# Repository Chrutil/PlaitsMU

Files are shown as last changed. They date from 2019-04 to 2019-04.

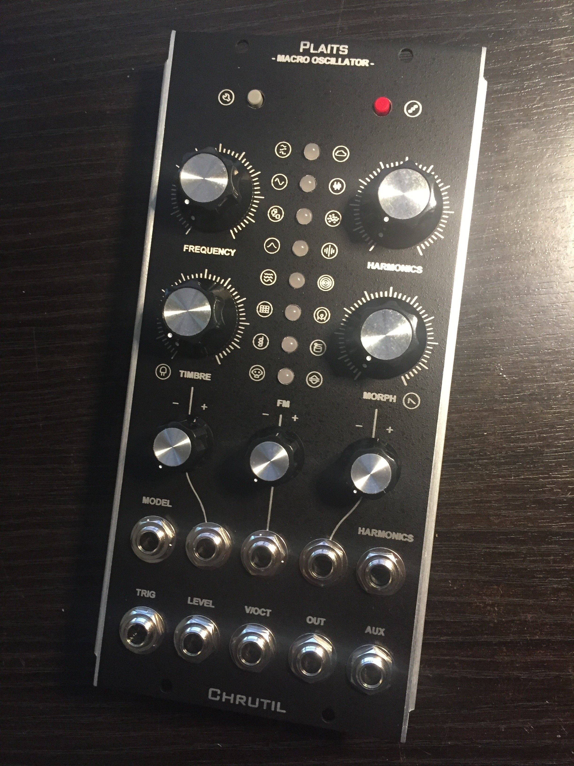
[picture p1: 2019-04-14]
front.jpg

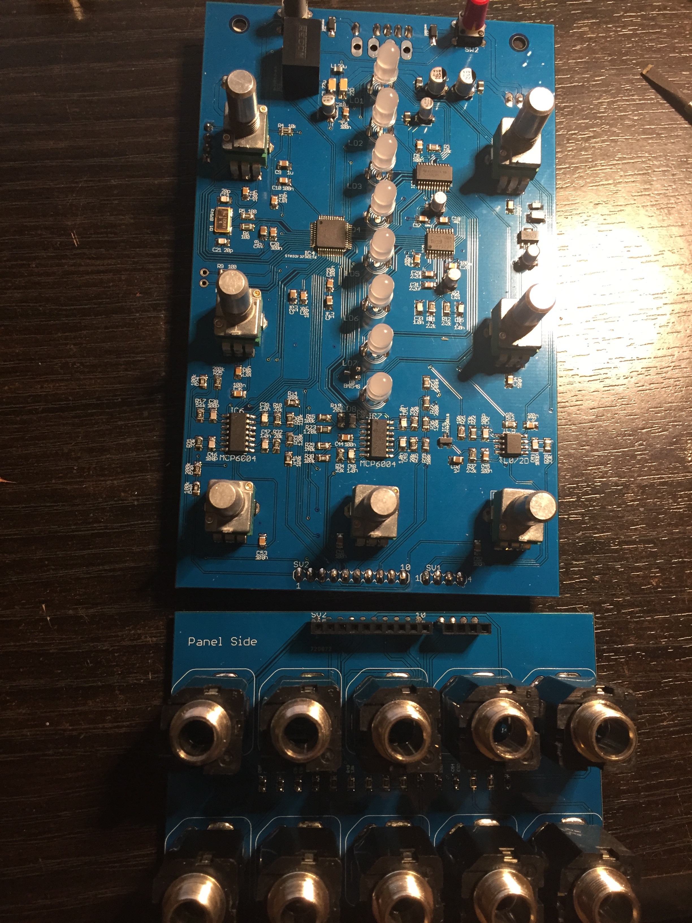
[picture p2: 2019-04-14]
populated_pcb.jpg

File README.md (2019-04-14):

# PlaitsMU
The Plaits Macro Oscillator ported to MU

This project is the Plaits Macro Oscillator by Mutable Instruments ported to MU large format modular.

The size of the PCB has been increased and the layout expanded for a 2MU module.
The footprint of most components have been changed to a larger 0805 size, for an easier build.
A few components were left at 0603 size where I could not find a suitable replacement.
The Power connector is a Synthesizers.com standard using -15v/+15v.
There are 12v power regulators added to feed the module the +/-12v it expects.
There is also a footprint for a MOTM power connector, but it is untested. 
I also suspect the io PCB is too wide for a double wide MOTM panel, but I have only tested MU so you are on your own there.

The best way is to select components is to look at the original BOM and pick the appropriate components with the expanded footprint.
I added a file with my parts selection, with no guarantees that I got it correct.

The STM32 mcu is the same as the original module and a very fine pitched IC with 0.5mm pitch so that will be the most challenging part.
I suggest starting with that one to make sure you got that right before populating the rest of the board.

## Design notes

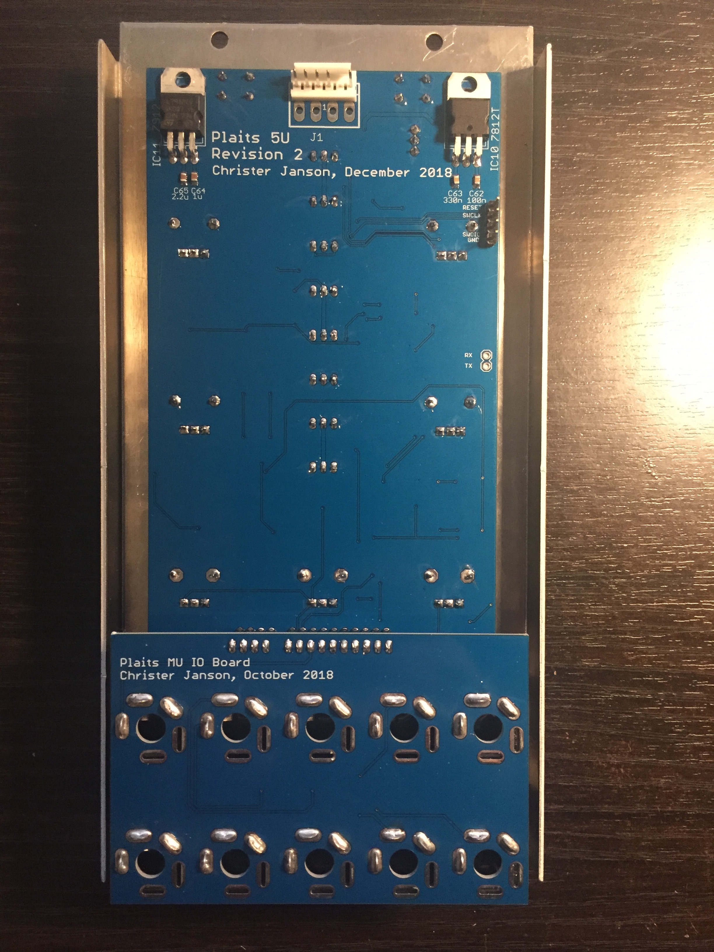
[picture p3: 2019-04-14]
back.jpg

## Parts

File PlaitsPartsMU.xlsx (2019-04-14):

Plaits, v5.0 [With MU replacement parts in green Column I]
Index | Qty | Description | Specs | Value | Package | Ref. Mouser | References | MU Part
SMT parts
R3, R4, R16, R21, R45, R48, R49, R50, R51 | 9 | Resistor | <=1%, 100mW | 10k | 0402 | 667-ERJ-2RKF1002X |  | Standard 0805 resistor
R5, R6, R9, R10 | 4 | Resistor | <=1%, 100mW | 100 | 0402 | 667-ERJ-2RKF1000X |  | Standard 0805 resistor
R11, R12, R37 | 3 | Resistor | <=1%, 100mW | 2.2k | 0402 | 667-ERJ-2RKF2201X |  | Standard 0805 resistor
R13, R14, R15, R24, R38, R39, R40, R41 | 8 | Resistor | <=1%, 100mW | 100k | 0402 | 667-ERJ-2RKF1003X |  | Standard 0805 resistor
R17 | 1 | Resistor | <=1%, 100mW | 56k | 0402 | 667-ERJ-2RKF5602X |  | Standard 0805 resistor
R18, R20, R22, R28, R31, R34 | 6 | Resistor | <=1%, 100mW | 33k | 0402 | 667-ERJ-2RKF3302X |  | Standard 0805 resistor
R19, R32, R35 | 3 | Resistor | <=1%, 100mW | 20k | 0402 | 667-ERJ-2RKF2002X |  | Standard 0805 resistor
R23, R33, R36 | 3 | Resistor | <=1%, 100mW | 120k | 0402 | 667-ERJ-2RKF1203X |  | Standard 0805 resistor
R25, R27, R30 | 3 | Resistor | <=1%, 100mW | 200k | 0402 | 667-ERJ-2RKF2003X |  | Standard 0805 resistor
R26 | 1 | Resistor | <=1%, 100mW | 110k | 0402 | 667-ERJ-2RKF1103X |  | Standard 0805 resistor
R29 | 1 | Resistor | <=1%, 100mW | 140k | 0402 | 667-ERJ-2RKF1403X |  | Standard 0805 resistor
R46, R47 | 2 | Resistor | <= 1%, >= 200mW | 1.0k | 0603 | 667-ERJ-PA3D1001V | Panasonic ERJ-PA3D1001V | same
C1, C2, C13 | 3 | Capacitor, ceramic | >= 25V, X5R | 22u | 1206 | 81-GRM31CR61E226ME5L | Murata GRM31CR61E226ME15L | same | Mouser
C3, C7, C16, C22, C30 | 5 | Capacitor, electrolytic | >= 16V | 10u | Panasonic A (3mm) | 647-UWX1C100MCL2 | Nichicon UWX1C100MCL2GB | same | Mouser
C4, C5 | 2 | Capacitor, electrolytic | >= 35V | 22u | Panasonic B (4mm) | 647-UCM1V220MCL1GS | Nichicon UCM1V220MCL1GS | 667-EEE-FT1V220AR | Mouser
C6, C8, C10, C11, C12, C15, C17, C18, C20, C23, C26, C27, C28, C32, C34, C36, C37, C44, C45, C51, C52, C53 | 22 | Capacitor, ceramic | >= 25V, X5R | 100n | 0402 | 81-GRM155R61E104KA7D | Murata GRM155R61E104KA87D | 100nF 0.1uF 50V SMD Ceramic Chip Capacitor 0805 | Taydaelectronics
C9, C19, C24, C25, C50 | 5 | Capacitor, ceramic | >= 25V, X6S | 1u | 0402 | 81-GRM155C81E105ME1D | Murata GRM155C81E105ME11D | 81-GRT21BC81E105KE3L | Mouser
C14, C21 | 2 | Capacitor, ceramic | >=25V, C0G, <= 5% | 20p | 0402 | 81-GRM1555C1E200JA1D | Murata GRM1555C1E200JA01D | 80-C0805C200J3G | Mouser
C29, C31 | 2 | Capacitor, ceramic | >= 25V, X5R | 2.2u | 0805 | 810-C2012X5R1E225K | TDK C2012X5R1E225K125AC | 810-C2012X5R1E225K0C | Mouser
C33, C35, C39, C40, C41, C47, C48, C49 | 8 | Capacitor, ceramic | >= 25V, C0G, <= 5% | 1n | 0402 | 81-GRM1555C1H102JA1D | Murata GRM1555C1H102JA01D | 80-C0805C102J5G7210 | Mouser
C38, C42, C43, C46 | 4 | Capacitor, ceramic | >= 25V, C0G, <= 5% | 100p | 0402 | 81-GRM1555C1H101JA1D | Murata GRM1555C1H101JA01D | 81-GCM2165C1H101JA6D | Mouser
C54, C55, C56, C57, C58, C59, C60, C61 | 8 | Ceradiode |  |  | 0603 | 871-B72500D160H60 | Epcos / TDK B72500D160H60 | same
L1 | 1 | Inductor |  | 33u | 0805 | 810-MLZ2012M330WT000 | TDK MLZ2012M330WT000 | same
L2, L3, L4, L5 | 4 | EMI Filter Bead | >= 1k ohm, 300mA |  | 0603 | 710-742792664 | Würth Electronics 742792664 | 963-BK2125HS102-T | Mouser
D1, D2 | 2 | 1N5819HW diode |  |  | SOD123 | 621-1N5819HW-F | Diodes Inc 1N5819HW-7-F | same
D3 | 1 | BAT54SLT1G diode |  |  | SOT23 | 863-BAT54SLT1G | ON Semi BAT54SLT1G (replaces BAT54S) | same
IC2 | 1 | TLC59281DBQ 16ch LED driver |  |  | TSSOP24 | 595-TLC59281DBQR | Texas Instruments TLC59281DBQR | same
IC3 | 1 | LD2981ABU33 LDO regulator | 3.3V |  | SOT89-3 | 511-LD2981ABU33 | ST LD2981ABU33TR | same
IC4 | 1 | STM32F373CCT6, Cortex M4 256k flash |  |  | LQFP48 | 511-STM32F373CCT6 | ST STM32F373CCT6 | same
IC5 | 1 | PCM5100APW Audio DAC |  |  | SSOP20 | 595-PCM5100APWR | Texas Instruments PCM5100APWR | same
IC6, IC7 | 2 | MCP6004 quad op-amp R2R IO |  |  | TSSOP14 | 579-MCP6004-I/ST | Microchip MCP6004-I/ST | 579-MCP6004T-I/SL | Mouser
IC8 | 1 | TL072 dual op-amp |  |  | TSSOP8 | 595-TL072CPWR | Texas Instruments TL072CPWR | TL072 Dual Operational Amplifier J-FET SOIC-8 TL072ACDR | Taydaelectronics
IC9 | 1 | LM4040 Shunt Vref | C grade (0.5%, 100ppm) | 10V | SOT23 | 595-LM4040C10IDBZR | Texas Instruments LM4040C10IDBZ | same
Q1 | 1 | Crystal | <= 20ppm | 8MHz | 6mm x 3.6mm | 815-ABMM2-8-E2T | Abracon ABMM2-8.000MHZ-E2-T | same
PTH parts, top side
IC1 | 1 | DC-DC converter R-78E3.3-0.5 | 3.3V, 500mA |  |  | 919-R-78E3.3-0.5 | Recom R-78E3.3-0.5 | same
J1, J2, J3, J4, J5, J6, J7, J8, J9, J10 | 10 | Vertical jack connector |  |  |  |  | https://www.thonk.co.uk/shop/thonkiconn/ | 502-112AX | Mouser
LED1, LED2, LED3, LED4, LED5, LED6, LED7, LED8 | 8 | LED 3mm red/green common anode |  |  |  | 696-SSLLX3059IGWCA | Lumex SSL-LX3059IGW-CA | 604-WP59EGW/CA | Mouser
- | 8 | LED holder, 0.3in |  |  |  | 749-ERM1-300 | Bivar ERM 1-300 | not used
R1, R2, R7, R8 | 4 | 10k linear pot, 15mm shaft |  |  |  |  | https://www.thonk.co.uk/shop/alpha-9mm-pots/ | 10K OHM Linear Taper Potentiometer Round Shaft PCB 9mm | Taydaelectronics
R42, R43, R44 | 3 | 10k linear pot, 25mm shaft with marker |  |  |  |  | https://www.thonk.co.uk/shop/ttpots/ | 10K OHM Linear Taper Potentiometer Round Shaft PCB 9mm | Taydaelectronics
SW1, SW2 | 2 | Switch, 6mm |  |  |  | 612-TL1105SP-250 | E-switch TL1105SPF250Q | same
- | 2 | Cap for switch |  |  |  | 612-1R-BK | E-switch 1RBLK | 612-1R-LGR, 612-1R-RD | Mouser. I used 1 Light Grey and 1 Red cap since my panel is monochrome.
mu Specific parts, bottom side
 | 1 | Female Pin Header 10 Pin |  |  |  |  |  | 10 Pin 2.54mm Single Row Female Pin Header | Taydaelectronics
 | 1 | Female Pin Header 4 Pin |  |  |  |  |  | 4 Pin 2.54mm Single Row Female Pin Header | Taydaelectronics
 | 1 | Male Pin Header 10 pin and two 4 pin. Buy a 40 pin and cut to length. |  |  |  |  |  | 40 Pin 2.54mm Single Row Pin Header Strip | Taydaelectronics
 | 1 | 12 Volt Regulator |  |  |  |  |  | L7812CV LM7812 L7812 7812 Voltage Regulator IC + 12V 1.5A | Taydaelectronics
 | 1 | -12 Volt Regulator |  |  |  |  |  | L7912CV LM7912 L7912 7912 Voltage Regulator IC -12V 1.5A | Taydaelectronics
C62 | 1 | Capacitor, ceramic |  | 100n | 0805 |  |  | 100nF 0.1uF 50V SMD Ceramic Chip Capacitor 0805 | Taydaelectronics
C63 | 1 | Capacitor, ceramic |  | 330n | 0805 |  |  | 330nF 0.33uF 50V SMD Ceramic Chip Capacitor 0805 | Taydaelectronics
C64 | 1 | Capacitor, ceramic |  | 1u | 0805 |  |  | 81-GRT21BC81E105KE3L | Mouser
C65 | 1 | Capacitor, ceramic |  | 2.2u | 0805 |  |  | 963-TMK212ABJ225MD-T | Mouser

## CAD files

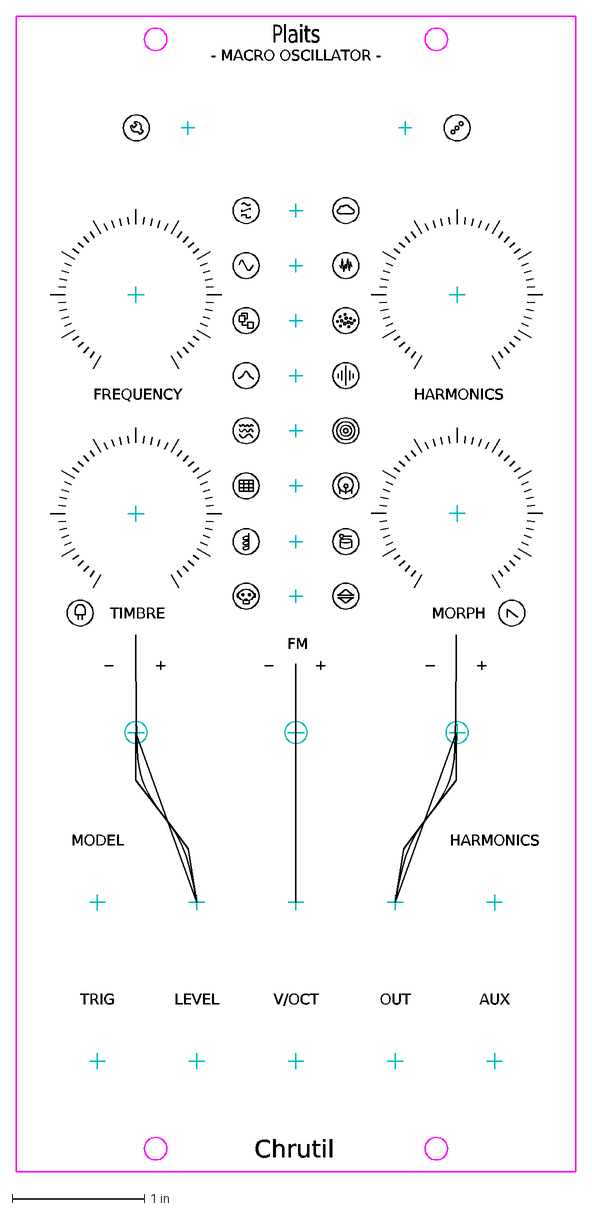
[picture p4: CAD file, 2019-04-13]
panel/MUPlaitsPanel.dxf
Plaits
Chrutil
- MACRO OSCILLATOR -
FREQUENCY
TIMBRE
MORPH
HARMONICS
TRIG
LEVEL
V/OCT
OUT
AUX
MODEL
FM

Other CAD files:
panel/MUPlaitsPanel.dwg

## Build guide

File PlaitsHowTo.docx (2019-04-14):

# Plaits Macro Oscillator MU

## Christer Janson

chrutil at hotmail dotcom

Here is a quick description of this project – a port of the Plaits Macro Oscillator to large format MU modular. Any errors in the following description and the associated PCBs and Panel are my own. There are no guarantees I got it right, but I did build several of these modules that appear to be working well with these instructions and drawings.

If you find an issue with this content, please contact me by email. Please realize that this email gets a lot of spam and multiple emails might be required to get my attention.

## Building

Populating the PCB is relatively straight forward.

Some components like the STM32 have very small pins and can take some practice to solder. There are multiple videos on youtube showing how to do this. I advise doing this part first and make sure you got it right before populating the rest of the board. There are a few other components that are very small, but the majority of components has been changed to larger footprint.

The connection between the two PCBs are done using two pine headers – a 10 pin and a 4 pin. The male 10 and 4 pin connectors go on the backside of the main pcb. The female counterparts are placed on the panel side of the ioboard pcb.

Also on the back side of the main pcb is the 4 pin male header serving as the programming port for connecting the ST-LINK V/2

## Programming

First setup the Mutable Instruments development environment.

There are many ways to do this and lots of instructions online. The following way worked for me.

I used the instructions located at: https://github.com/pichenettes/mutable-dev-environment

Once the environment is setup, in a Command Prompt window, CD into the installation folder (Assumed to D:\MutableDevEnv below)

D:

Cd \MutableDevEnv

Vagrant up

Vagrant ssh

[Now you should be logged in to the virtual machine]

[Build the binaries]

make -f plaits/bootloader/makefile hex

make -f plaits/makefile

[Then when the binaries are built]

[Make sure the Plaits module is powered and connected to ST-LINK V/2 as per the diagram below]

[Program the Plaits module]

make -f plaits/makefile upload

I used ST-LINK V/2 for programming the Plaits module. This is what I did on a PC running Windows 7.

Install ST-LINK V/2 drivers

ST-LINK V/2 should be connected to the PC before starting the Vagrant environment

Connect the ST-LINK V/2 to the Plaits module using the four pin connector on Plaits to the following pins on ST-LINK V/2. Do not forget to jumper pin 1 to pin 19 on the ST-LINK V/2

1 <-–> 19 jumper cable
7 SWDIO
9 SWCLK
15 Reset
4 GND

Here is a diagram of the connection, make sure the ST-LINK V/2 faces the right way. In the diagram the ‘key’ is facing left.

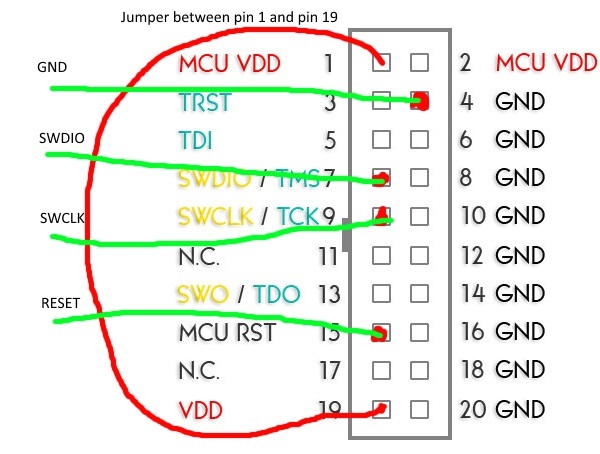
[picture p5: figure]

Last, many, many thanks to Olivier and Mutable Instruments for allowing us access to his IP.

This project is a small attempt to pay it forward.

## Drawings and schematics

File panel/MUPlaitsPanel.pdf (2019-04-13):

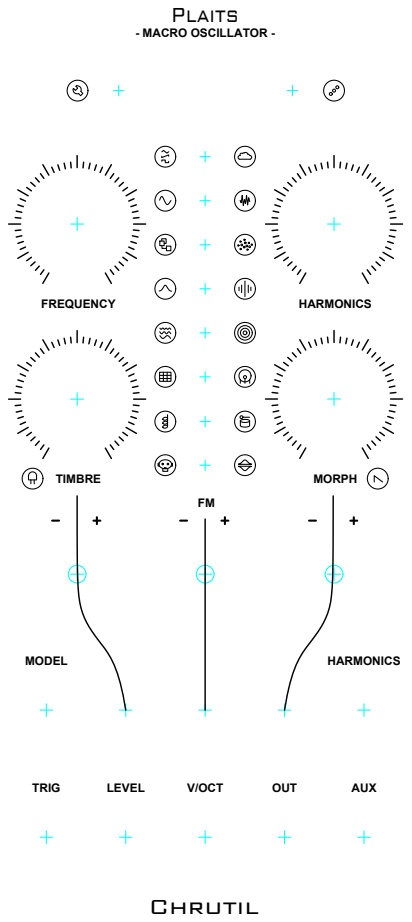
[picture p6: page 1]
- MACRO OSCILLATOR -

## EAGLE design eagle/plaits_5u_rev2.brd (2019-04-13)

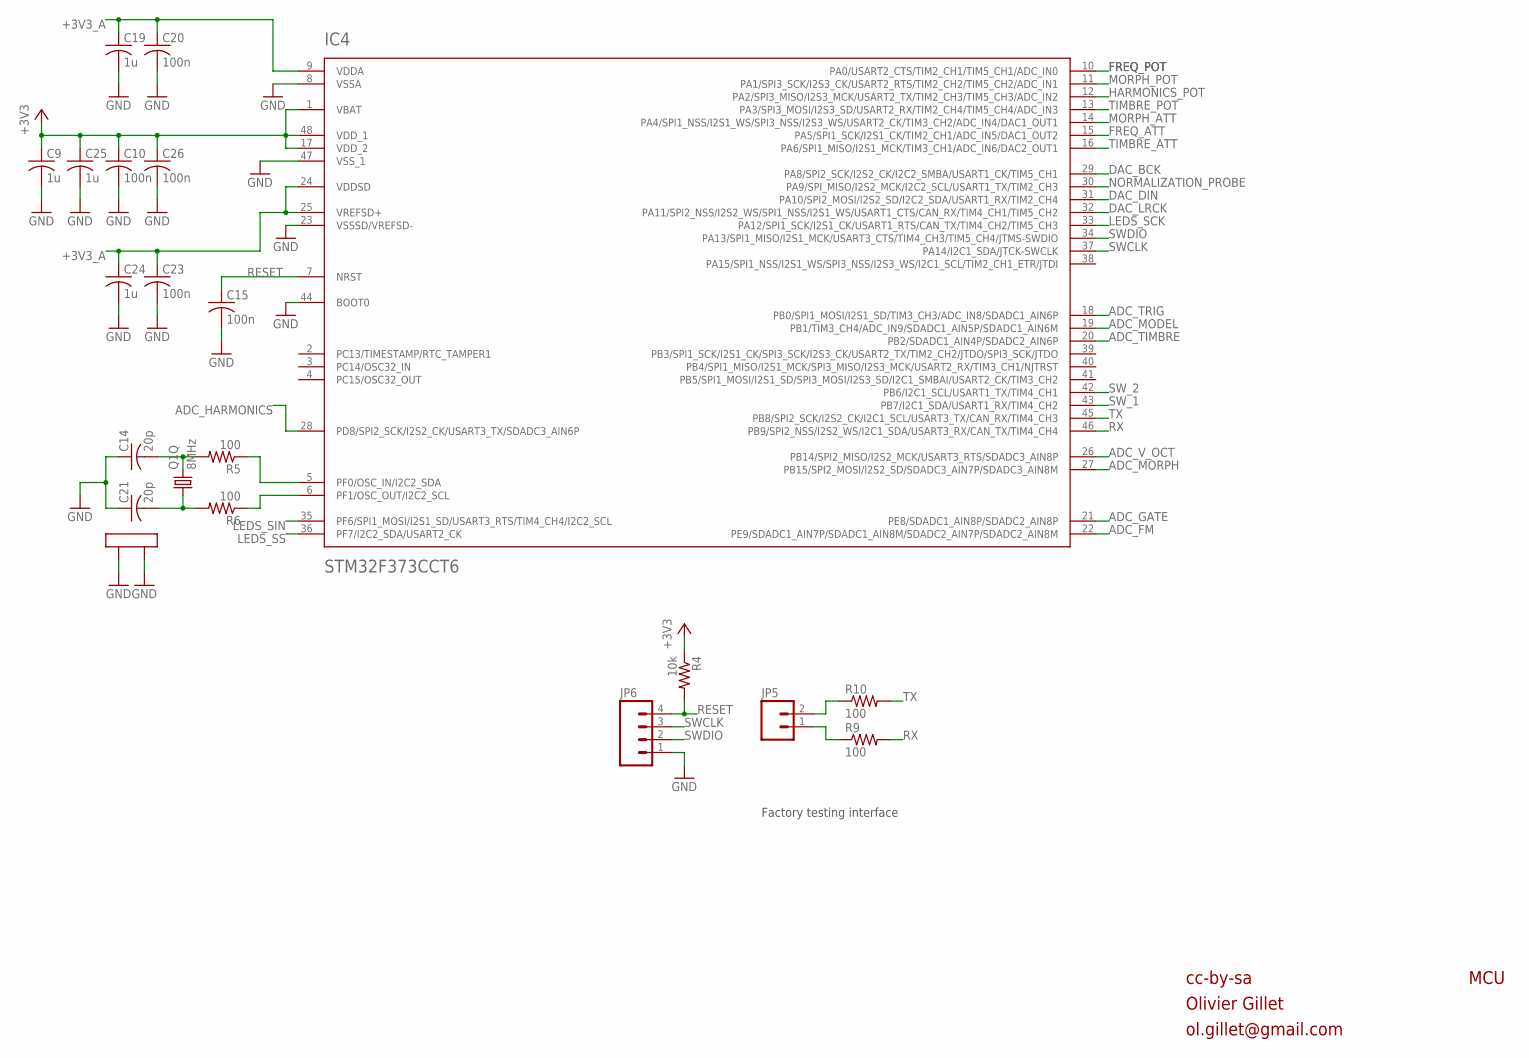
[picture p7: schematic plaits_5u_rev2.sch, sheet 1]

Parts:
C9, C19, C24, C25: 1u; C0805
C10, C15, C20, C23, C26: 100n; C0805
C14, C21: 20p; C0805
IC4: STM32F373CCT6; LQFP48
JP5: M02PTH; 1X02
JP6: M04PTH; 1X04
Q1: 8MHz; CTS406
R4: 10k; R0805
R5, R6, R9, R10: 100; R0805

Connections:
+3V3: C9.1, C10.1, C25.1, C26.1, IC4.1 (VBAT), IC4.17 (VDD_2), IC4.48 (VDD_1), R4.1; also elsewhere on the board
+3V3_A: C19.1, C20.1, C23.1, C24.1, IC4.9 (VDDA), IC4.24 (VDDSD), IC4.25 (VREFSD+); also elsewhere on the board
ADC_FM: IC4.22 (PE9/SDADC1_AIN7P/SDADC1_AIN8M/SDADC2_AI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); also elsewhere on the board
ADC_GATE: IC4.21 (PE8/SDADC1_AIN8P/SDADC2_AIN8P); also elsewhere on the board
ADC_HARMONICS: IC4.28 (PD8/SPI2_SCK/I2S2_CK/USART3_TX/SDADC3_A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); also elsewhere on the board
ADC_MODEL: IC4.19 (PB1/TIM3_CH4/ADC_IN9/SDADC1_AIN5P/SDADC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); also elsewhere on the board
ADC_MORPH: IC4.27 (PB15/SPI2_MOSI/I2S2_SD/SDADC3_AIN7P/SDA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); also elsewhere on the board
ADC_TIMBRE: IC4.20 (PB2/SDADC1_AIN4P/SDADC2_AIN6P); also elsewhere on the board
ADC_TRIG: IC4.18 (PB0/SPI1_MOSI/I2S1_SD/TIM3_CH3/ADC_IN8/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); also elsewhere on the board
ADC_V_OCT: IC4.26 (PB14/SPI2_MISO/I2S2_MCK/USART3_RTS/SDAD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); also elsewhere on the board
DAC_BCK: IC4.29 (PA8/SPI2_SCK/I2S2_CK/I2C2_SMBA/USART1_C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); also elsewhere on the board
DAC_DIN: IC4.31 (PA10/SPI2_MOSI/I2S2_SD/I2C2_SDA/USART1_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); also elsewhere on the board
DAC_LRCK: IC4.32 (PA11/SPI2_NSS/I2S2_WS/SPI1_NSS/I2S1_WS/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); also elsewhere on the board
FREQ_ATT: IC4.15 (PA5/SPI1_SCK/I2S1_CK/TIM2_CH1/ADC_IN5/D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); also elsewhere on the board
FREQ_POT: IC4.10 (PA0/USART2_CTS/TIM2_CH1/TIM5_CH1/ADC_IN0); also elsewhere on the board
GND: C9.2, C10.2, C14.1, C15.2, C19.2, C20.2, C21.1, C23.2, C24.2, C25.2, C26.2, IC4.8 (VSSA), IC4.23 (VSSSD/VREFSD-), IC4.44 (BOOT0), IC4.47 (VSS_1), JP6.1, Q1.2 (LID1), Q1.4 (LID2); also elsewhere on the board
HARMONICS_POT: IC4.12 (PA2/SPI3_MISO/I2S3_MCK/USART2_TX/TIM2_C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); also elsewhere on the board
LEDS_SCK: IC4.33 (PA12/SPI1_SCK/I2S1_CK/USART1_RTS/CAN_TX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); also elsewhere on the board
LEDS_SIN: IC4.35 (PF6/SPI1_MOSI/I2S1_SD/USART3_RTS/TIM4_C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); also elsewhere on the board
LEDS_SS: IC4.36 (PF7/I2C2_SDA/USART2_CK); also elsewhere on the board
MORPH_ATT: IC4.14 (PA4/SPI1_NSS/I2S1_WS/SPI3_NSS/I2S3_WS/U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); also elsewhere on the board
MORPH_POT: IC4.11 (PA1/SPI3_SCK/I2S3_CK/USART2_RTS/TIM2_CH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); also elsewhere on the board
unnamed: IC4.5 (PF0/OSC_IN/I2C2_SDA), R5.1
unnamed: IC4.6 (PF1/OSC_OUT/I2C2_SCL), R6.1
unnamed: C14.2, Q1.3 (2), R5.2
unnamed: JP5.2, R10.1
unnamed: C21.2, Q1.1, R6.2
unnamed: JP5.1, R9.1
NORMALIZATION_PROBE: IC4.30 (PA9/SPI_MISO/I2S2_MCK/I2C2_SCL/USART1_T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); also elsewhere on the board
RESET: C15.1, IC4.7 (NRST), JP6.4, R4.2
RX: IC4.46 (PB9/SPI2_NSS/I2S2_WS/I2C1_SDA/USART3_RX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), R9.2
SWCLK: IC4.37 (PA14/I2C1_SDA/JTCK-SWCLK), JP6.3
SWDIO: IC4.34 (PA13/SPI1_MISO/I2S1_MCK/USART3_CTS/TIM4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), JP6.2
SW_1: IC4.43 (PB7/I2C1_SDA/USART1_RX/TIM4_CH2); also elsewhere on the board
SW_2: IC4.42 (PB6/I2C1_SCL/USART1_TX/TIM4_CH1); also elsewhere on the board
TIMBRE_ATT: IC4.16 (PA6/SPI1_MISO/I2S1_MCK/TIM3_CH1/ADC_IN6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); also elsewhere on the board
TIMBRE_POT: IC4.13 (PA3/SPI3_MOSI/I2S3_SD/USART2_RX/TIM2_CH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); also elsewhere on the board
TX: IC4.45 (PB8/SPI2_SCK/I2S2_CK/I2C1_SCL/USART3_TX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), R10.2

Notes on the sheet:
cc-by-sa
Olivier Gillet
ol.gillet@gmail.com
MCU
Factory testing interface

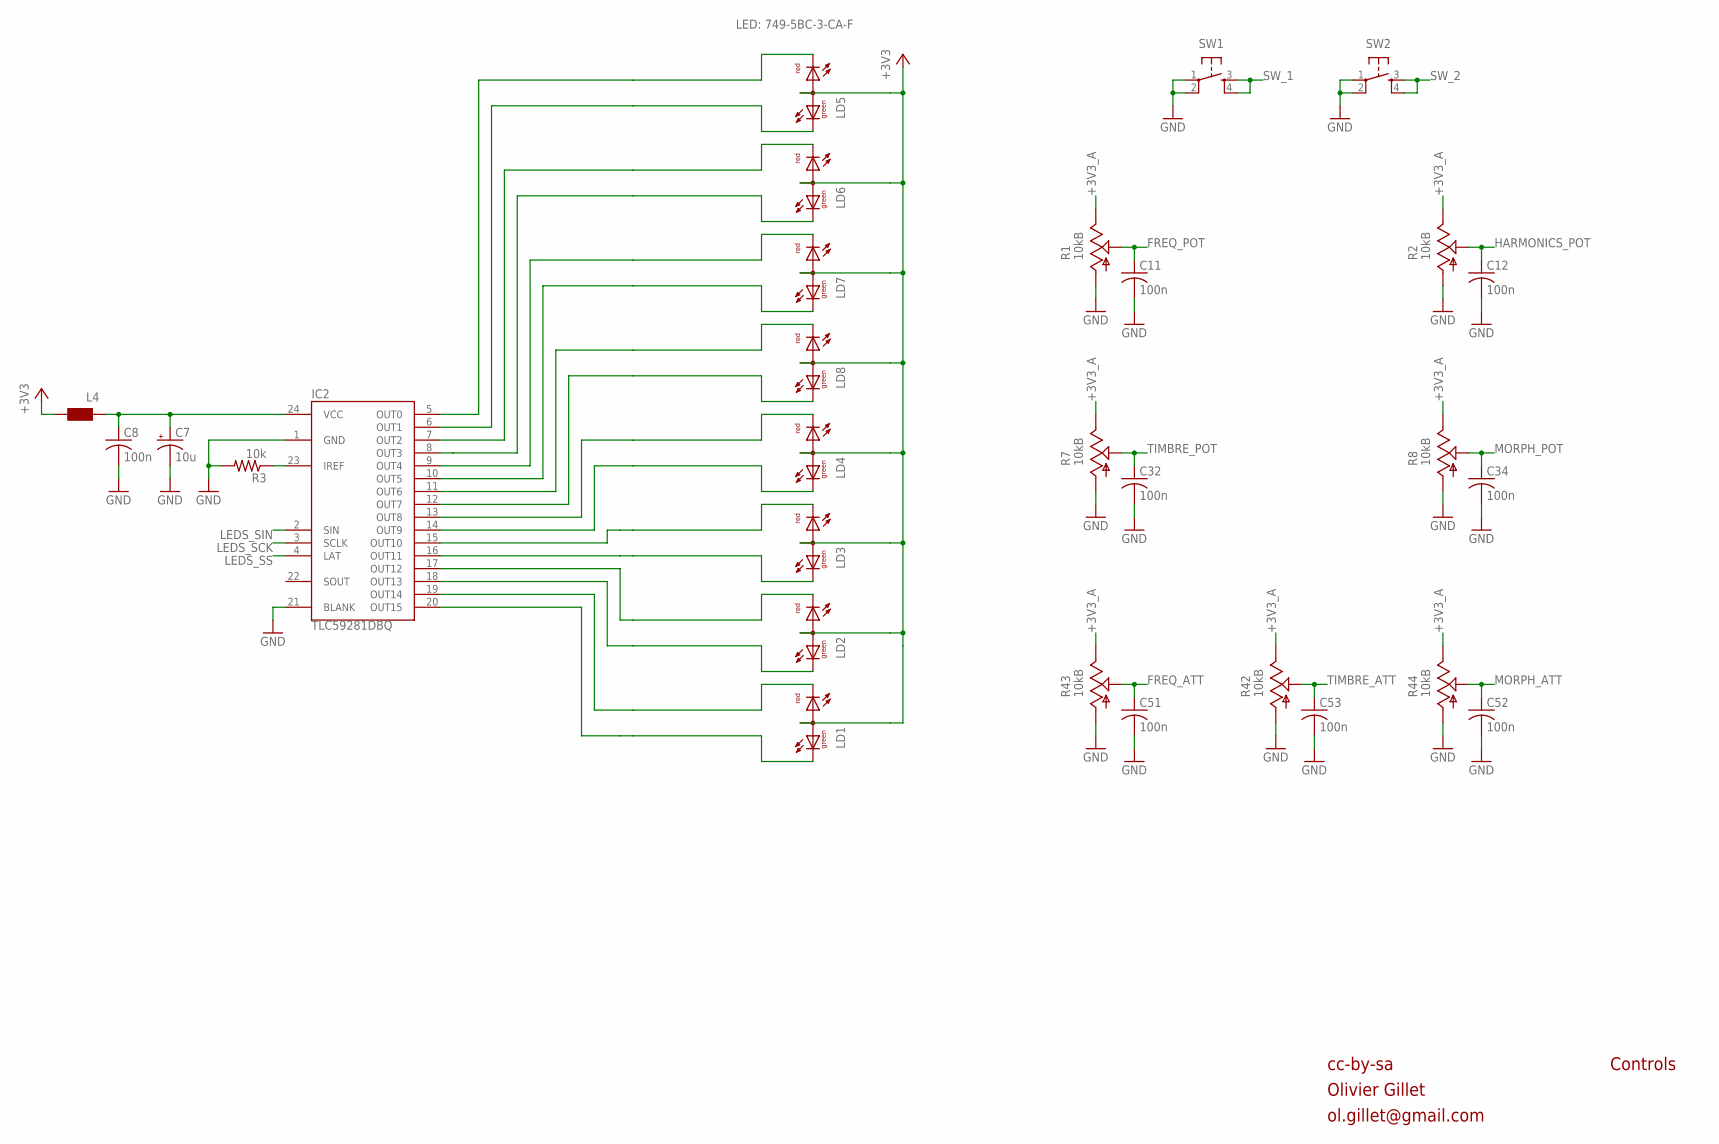
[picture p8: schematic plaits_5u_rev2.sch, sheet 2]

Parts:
C7: 10u; PANASONIC_A
C8, C11, C12, C32, C34, C51, C52, C53: 100n; C0805
IC2: TLC59281DBQ; TSSOP24_0635
L4: WE-CBF_0805; 0805
LD1, LD2, LD3, LD4, LD5, LD6, LD7, LD8: DUOLED-RG-A; DUOLED-A-5MM
R1, R2, R7, R8: 10kB; ALPS_POT_VERTICAL_PS
R3: 10k; R0805
R42, R43, R44: 10kB; ALPS_POT_VERTICAL
SW1, SW2: TAC_SWITCHPTH; TACTILE-PTH

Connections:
+3V3: L4.2, LD1.A, LD2.A, LD3.A, LD4.A, LD5.A, LD6.A, LD7.A, LD8.A; also elsewhere on the board
+3V3_A: R1.P$1 (E), R2.P$1 (E), R7.P$1 (E), R8.P$1 (E), R42.P$1 (E), R43.P$1 (E), R44.P$1 (E); also elsewhere on the board
FREQ_ATT: C51.1, R43.P$2 (S); also elsewhere on the board
FREQ_POT: C11.1, R1.P$2 (S); also elsewhere on the board
GND: C7.-, C8.2, C11.2, C12.2, C32.2, C34.2, C51.2, C52.2, C53.2, IC2.1 (GND), IC2.21 (BLANK), R1.P$3 (A), R2.P$3 (A), R3.2, R7.P$3 (A), R8.P$3 (A), R42.P$3 (A), R43.P$3 (A), R44.P$3 (A), SW1.1, SW1.2, SW2.1, SW2.2; also elsewhere on the board
HARMONICS_POT: C12.1, R2.P$2 (S); also elsewhere on the board
LEDS_SCK: IC2.3 (SCLK); also elsewhere on the board
LEDS_SIN: IC2.2 (SIN); also elsewhere on the board
LEDS_SS: IC2.4 (LAT); also elsewhere on the board
MORPH_ATT: C52.1, R44.P$2 (S); also elsewhere on the board
MORPH_POT: C34.1, R8.P$2 (S); also elsewhere on the board
unnamed: IC2.12 (OUT7), LD8.CX (CG)
unnamed: IC2.11 (OUT6), LD8.CR
unnamed: IC2.10 (OUT5), LD7.CX (CG)
unnamed: IC2.9 (OUT4), LD7.CR
unnamed: IC2.8 (OUT3), LD6.CX (CG)
unnamed: IC2.13 (OUT8), LD4.CR
unnamed: IC2.7 (OUT2), LD6.CR
unnamed: IC2.14 (OUT9), LD4.CX (CG)
unnamed: IC2.6 (OUT1), LD5.CX (CG)
unnamed: IC2.15 (OUT10), LD3.CR
unnamed: IC2.16 (OUT11), LD3.CX (CG)
unnamed: IC2.17 (OUT12), LD2.CR
unnamed: IC2.18 (OUT13), LD2.CX (CG)
unnamed: IC2.19 (OUT14), LD1.CR
unnamed: IC2.5 (OUT0), LD5.CR
unnamed: IC2.20 (OUT15), LD1.CX (CG)
unnamed: C7.+, C8.1, IC2.24 (VCC), L4.1
unnamed: IC2.23 (IREF), R3.1
SW_1: SW1.3, SW1.4; also elsewhere on the board
SW_2: SW2.3, SW2.4; also elsewhere on the board
TIMBRE_ATT: C53.1, R42.P$2 (S); also elsewhere on the board
TIMBRE_POT: C32.1, R7.P$2 (S); also elsewhere on the board

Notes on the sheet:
cc-by-sa
Olivier Gillet
ol.gillet@gmail.com
Controls
LED: 749-5BC-3-CA-F

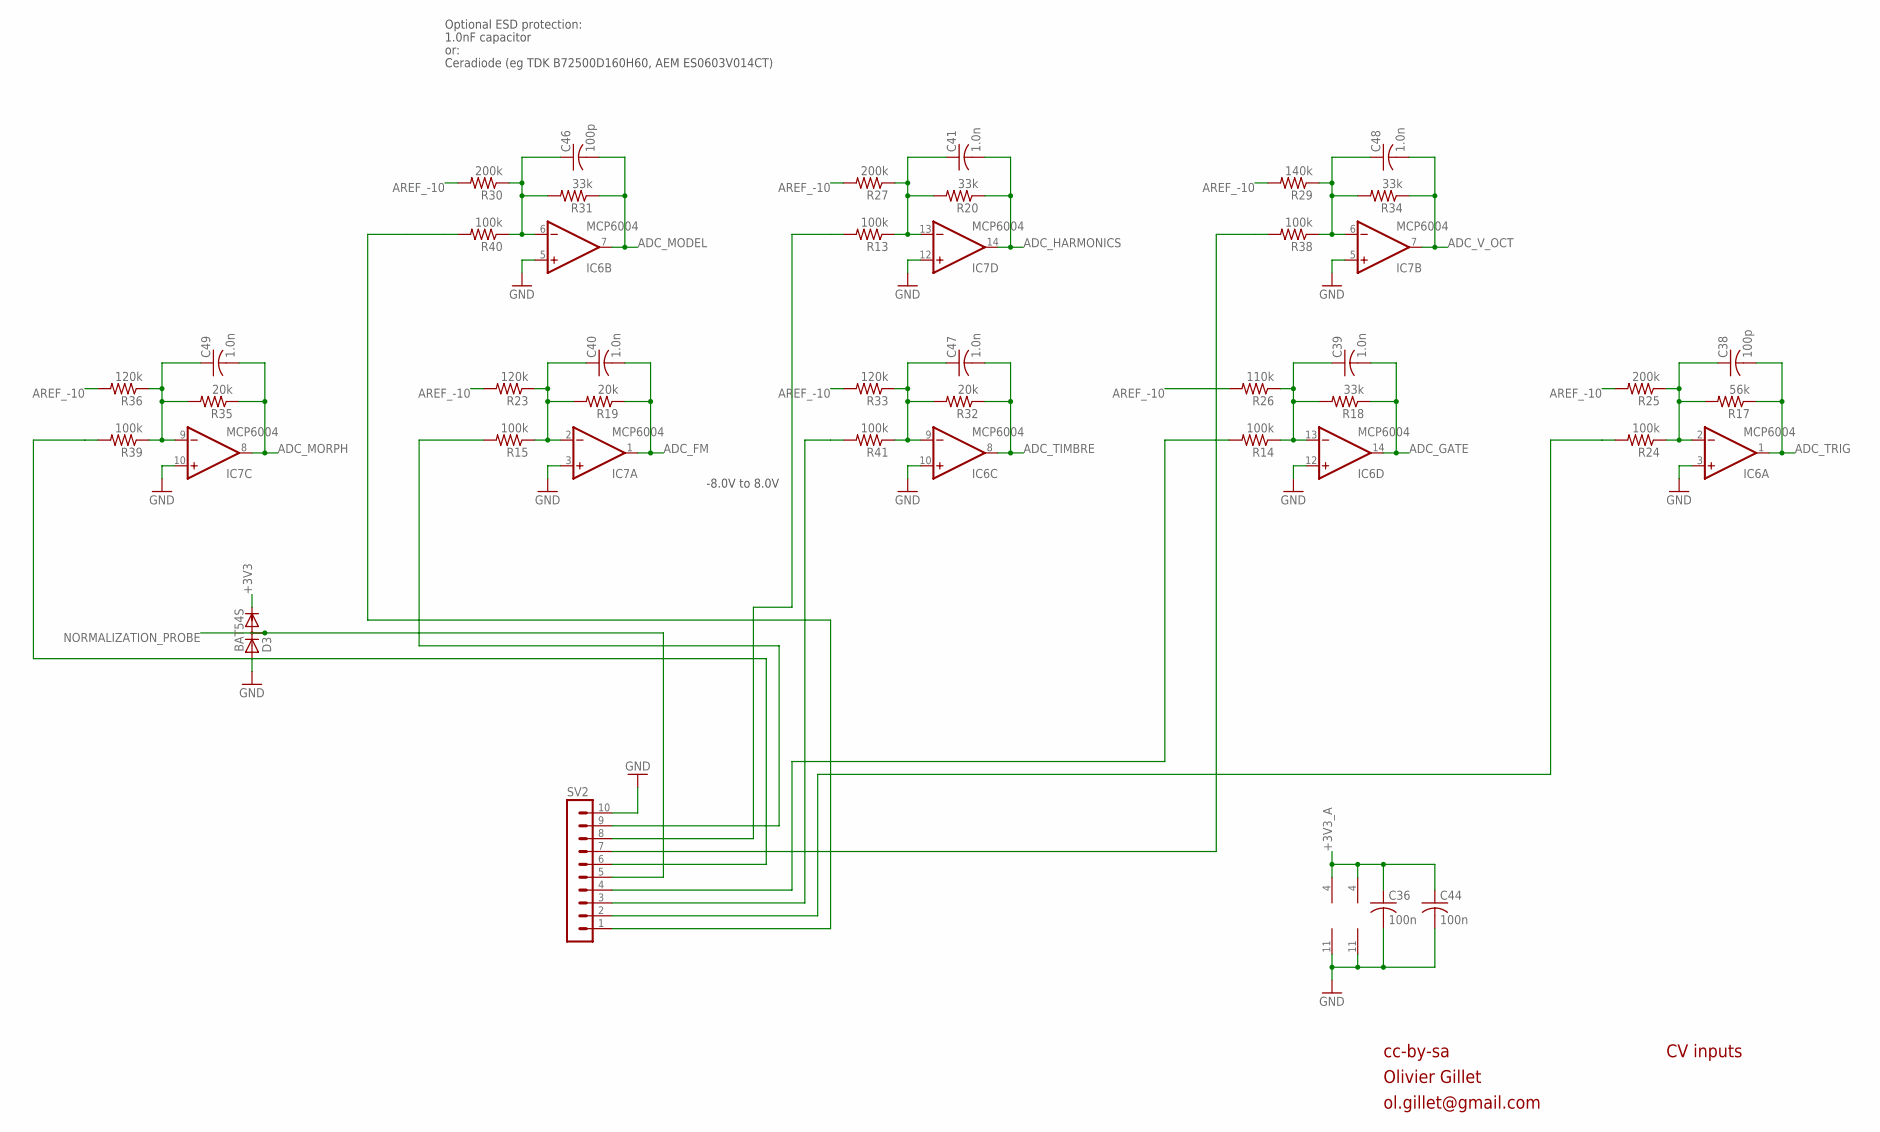
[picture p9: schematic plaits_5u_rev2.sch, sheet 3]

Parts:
C36, C44: 100n; C0805
C38, C46: 100p; C0805
C39, C40, C41, C47, C48, C49: 1.0n; C0805
D3: BAT54S; SOT23
IC6, IC7: MCP6004; SO14
R13, R14, R15, R24, R38, R39, R40, R41: 100k; R0805
R17: 56k; R0805
R18, R20, R31, R34: 33k; R0805
R19, R32, R35: 20k; R0805
R23, R33, R36: 120k; R0805
R25, R27, R30: 200k; R0805
R26: 110k; R0805
R29: 140k; R0805
SV2: MA10-1

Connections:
+3V3: D3.2 (C); also elsewhere on the board
+3V3_A: C36.1, C44.1, IC6.4 (V+), IC7.4 (V+); also elsewhere on the board
ADC_FM: C40.2, IC7.1 (OUT), R19.1; also elsewhere on the board
ADC_GATE: C39.2, IC6.14 (OUT), R18.1; also elsewhere on the board
ADC_HARMONICS: C41.2, IC7.14 (OUT), R20.1; also elsewhere on the board
ADC_MODEL: C46.2, IC6.7 (OUT), R31.1; also elsewhere on the board
ADC_MORPH: C49.2, IC7.8 (OUT), R35.1; also elsewhere on the board
ADC_TIMBRE: C47.2, IC6.8 (OUT), R32.1; also elsewhere on the board
ADC_TRIG: C38.2, IC6.1 (OUT), R17.1; also elsewhere on the board
ADC_V_OCT: C48.2, IC7.7 (OUT), R34.1; also elsewhere on the board
AREF_-10: R23.2, R25.2, R26.2, R27.2, R29.2, R30.2, R33.2, R36.2; also elsewhere on the board
FM_IN: R15.2, SV2.9
GATE_IN: R14.2, SV2.4
GATE_IN1: R24.2, SV2.2
GND: C36.2, C44.2, D3.1 (A), IC6.3 (+IN), IC6.5 (+IN), IC6.10 (+IN), IC6.11 (V-), IC6.12 (+IN), IC7.3 (+IN), IC7.5 (+IN), IC7.10 (+IN), IC7.11 (V-), IC7.12 (+IN), SV2.10; also elsewhere on the board
HARMONICS_IN: R13.2, SV2.8
MODEL_IN: R40.2, SV2.1
MORPH_IN: R39.2, SV2.6
unnamed: C38.1, IC6.2 (-IN), R17.2, R24.1, R25.1
unnamed: C39.1, IC6.13 (-IN), R14.1, R18.2, R26.1
unnamed: C48.1, IC7.6 (-IN), R29.1, R34.2, R38.1
unnamed: R41.2, SV2.3
unnamed: C49.1, IC7.9 (-IN), R35.2, R36.1, R39.1
unnamed: C40.1, IC7.2 (-IN), R15.1, R19.2, R23.1
unnamed: C46.1, IC6.6 (-IN), R30.1, R31.2, R40.1
unnamed: C47.1, IC6.9 (-IN), R32.2, R33.1, R41.1
unnamed: C41.1, IC7.13 (-IN), R13.1, R20.2, R27.1
NORMALIZATION_PROBE: D3.3 (AC), SV2.5; also elsewhere on the board
V_OCT_IN: R38.2, SV2.7

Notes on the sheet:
cc-by-sa
Olivier Gillet
ol.gillet@gmail.com
CV inputs
-8.0V to 8.0V
Optional ESD protection:
1.0nF capacitor
or:
Ceradiode (eg TDK B72500D160H60, AEM ES0603V014CT)

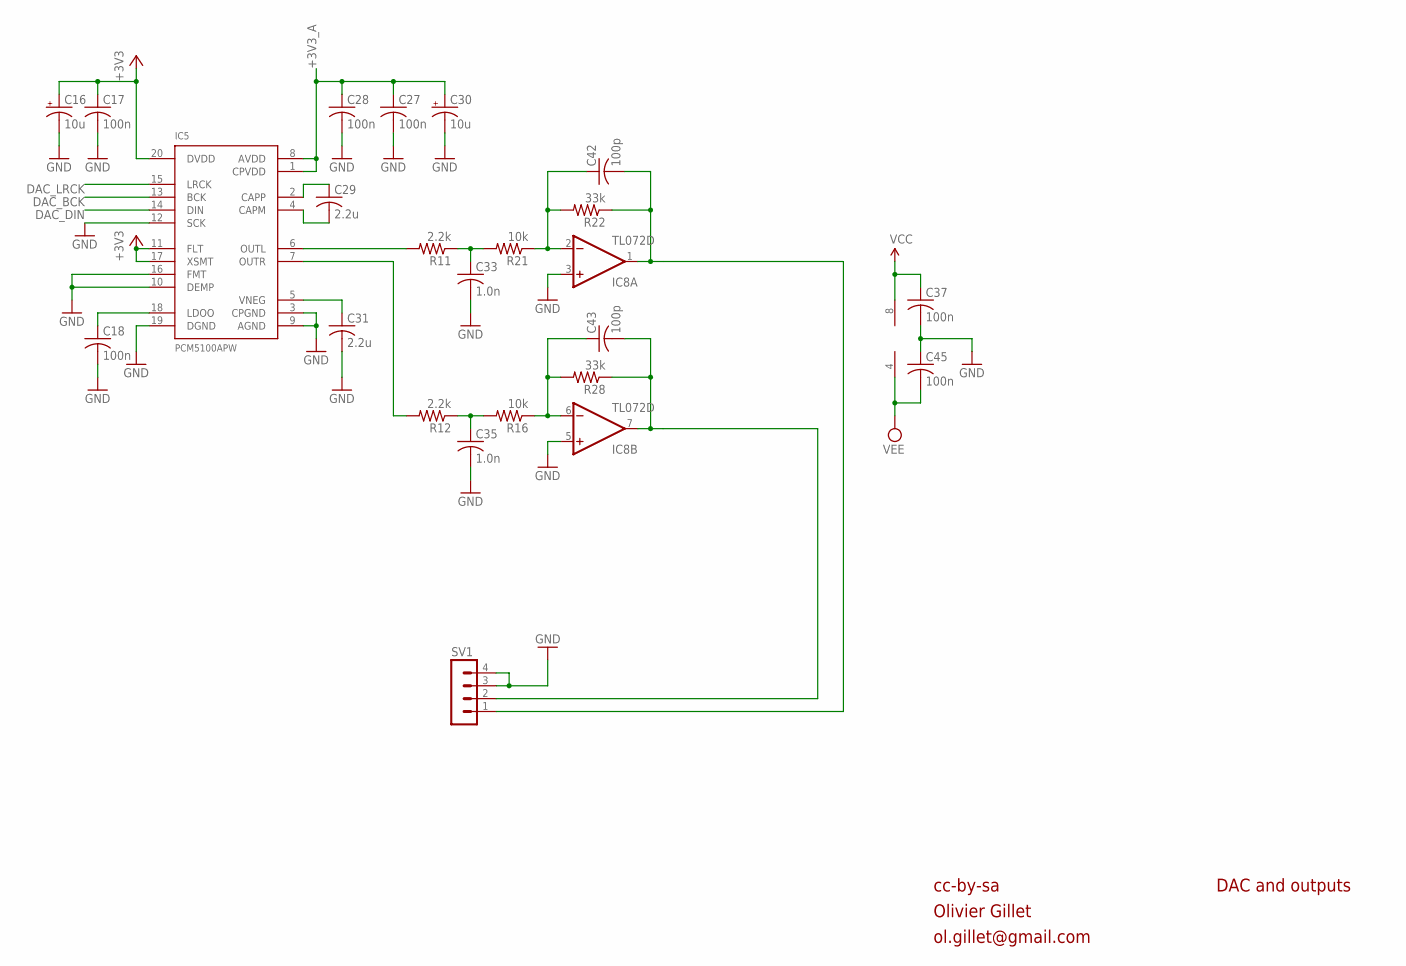
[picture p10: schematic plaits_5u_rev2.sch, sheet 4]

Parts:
C16, C30: 10u; PANASONIC_A
C17, C18, C27, C28, C37, C45: 100n; C0805
C29, C31: 2.2u; C0805
C33, C35: 1.0n; C0805
C42, C43: 100p; C0805
IC5: PCM5100APW; SSOP20
IC8: TL072D; SO08
R11, R12: 2.2k; R0805
R16, R21: 10k; R0805
R22, R28: 33k; R0805
SV1: MA04-1

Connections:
+3V3: C16.+, C17.1, IC5.11 (FLT), IC5.17 (XSMT), IC5.20 (DVDD); also elsewhere on the board
+3V3_A: C27.1, C28.1, C30.+, IC5.1 (CPVDD), IC5.8 (AVDD); also elsewhere on the board
DAC_BCK: IC5.13 (BCK); also elsewhere on the board
DAC_DIN: IC5.14 (DIN); also elsewhere on the board
DAC_LRCK: IC5.15 (LRCK); also elsewhere on the board
GND: C16.-, C17.2, C18.2, C27.2, C28.2, C30.-, C31.2, C33.2, C35.2, C37.2, C45.1, IC5.3 (CPGND), IC5.9 (AGND), IC5.10 (DEMP), IC5.12 (SCK), IC5.16 (FMT), IC5.19 (DGND), IC8.3 (+IN), IC8.5 (+IN), SV1.3, SV1.4; also elsewhere on the board
unnamed: C29.1, IC5.2 (CAPP)
unnamed: C29.2, IC5.4 (CAPM)
unnamed: IC5.6 (OUTL), R11.2
unnamed: C33.1, R11.1, R21.2
unnamed: C35.1, R12.1, R16.2
unnamed: C31.1, IC5.5 (VNEG)
unnamed: C18.1, IC5.18 (LDOO)
unnamed: IC5.7 (OUTR), R12.2
unnamed: C43.1, IC8.6 (-IN), R16.1, R28.2
unnamed: C43.2, IC8.7 (OUT), R28.1, SV1.2
unnamed: C42.1, IC8.2 (-IN), R21.1, R22.2
unnamed: C42.2, IC8.1 (OUT), R22.1, SV1.1
VCC: C37.1, IC8.8 (V+); also elsewhere on the board
VEE: C45.2, IC8.4 (V-); also elsewhere on the board

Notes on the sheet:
cc-by-sa
Olivier Gillet
ol.gillet@gmail.com
DAC and outputs

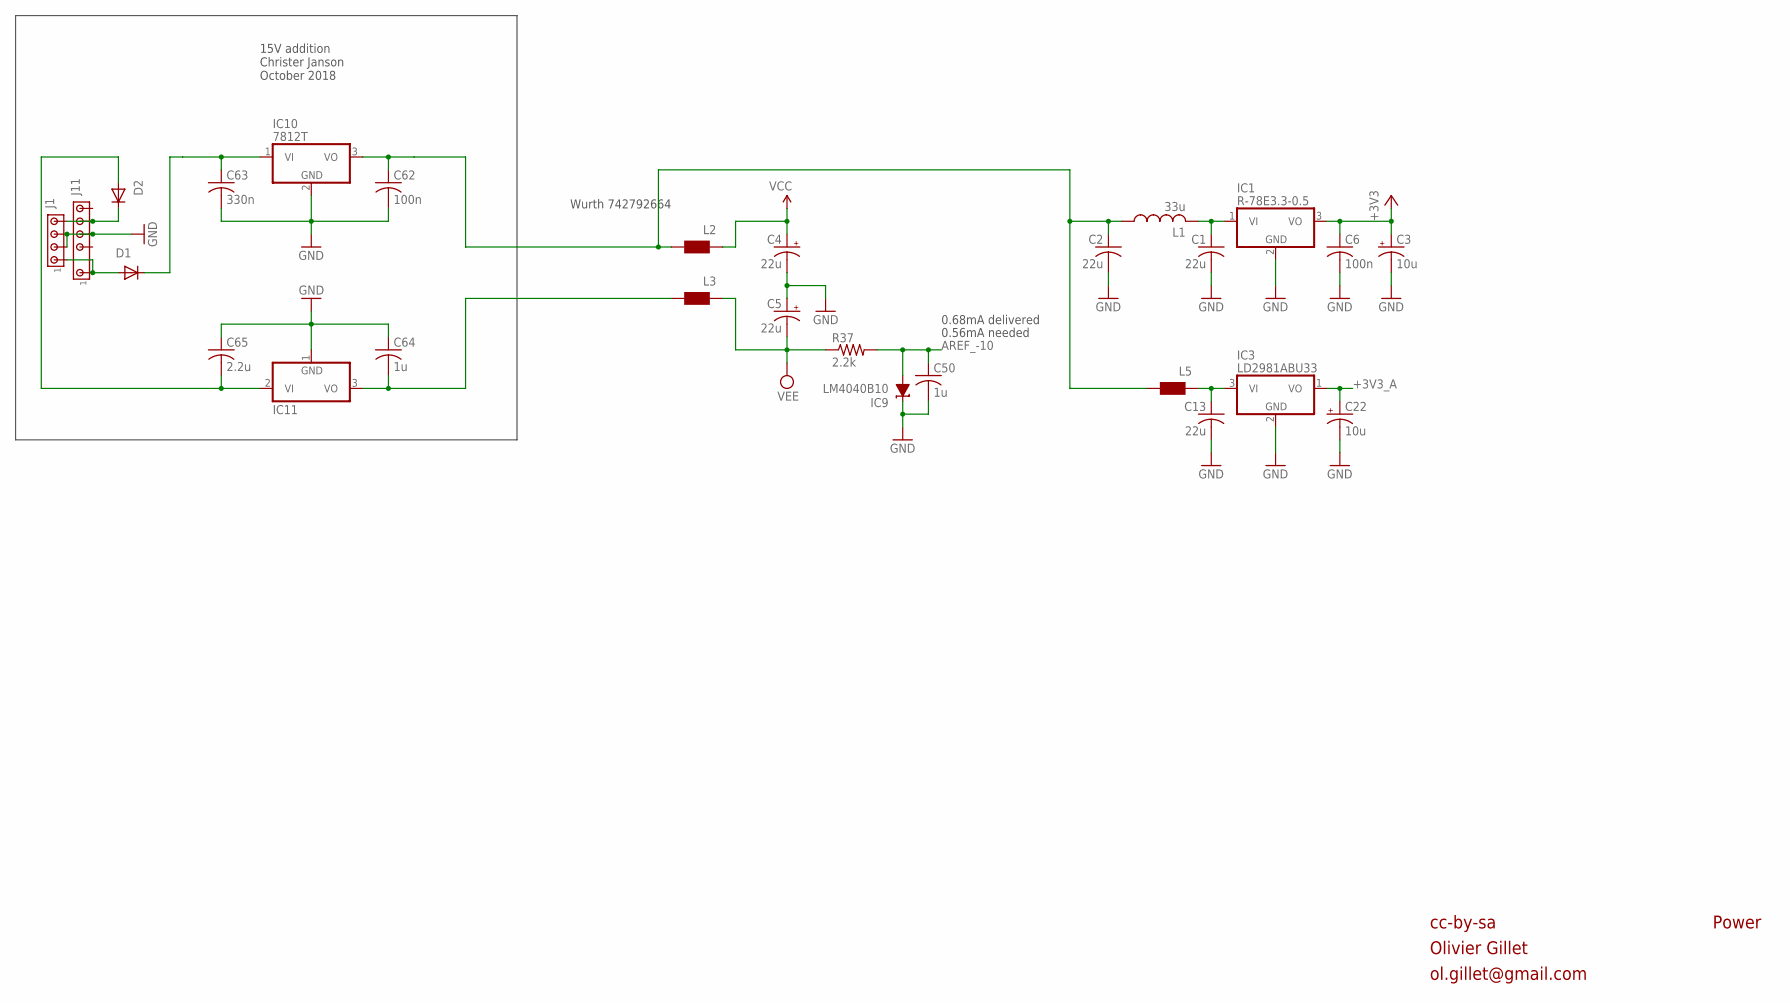
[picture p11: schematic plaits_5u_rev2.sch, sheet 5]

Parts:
C1, C2, C13: 22u; C1206
C3, C22: 10u; PANASONIC_A
C4, C5: 22u; PANASONIC_B
C6, C62: 100n; C0805
C50, C64: 1u; C0805
C63: 330n; C0805
C65: 2.2u; C0805
D1, D2: 1N5819HW; SOD123
IC1: R-78E3.3-0.5; WE78
IC3: LD2981ABU33; SOT89
IC9: LM4040B10; DBZ_R-PDSO-G3
IC10: 7812T; TO220H
IC11: 7912T; TO220H
J1: MTA04-156; 1X4MTA
J11: DOTCOMPOWER
L1: 33u; L2012C
L2, L3, L5: WE-CBF_0805; 0805
R37: 2.2k; R0805

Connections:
+3V3: C3.+, C6.1, IC1.3 (VO); also elsewhere on the board
+3V3_A: C22.+, IC3.1 (VO); also elsewhere on the board
AREF_-10: C50.1, IC9.2 (A), R37.2; also elsewhere on the board
GND: C1.2, C2.2, C3.-, C4.-, C5.+, C6.2, C13.2, C22.-, C50.2, C62.2, C63.2, C64.1, C65.1, IC1.2 (GND), IC3.2 (GND), IC9.1 (C), IC10.2 (GND), IC11.1 (GND), J1.2, J1.3, J11.4; also elsewhere on the board
unnamed: C1.1, IC1.1 (VI), L1.2
unnamed: D2.C, J1.4, J11.5
unnamed: C64.2, IC11.3 (VO), L3.2
unnamed: C13.1, IC3.3 (VI), L5.1
unnamed: C2.1, C62.1, IC10.3 (VO), L1.1, L2.2, L5.2
unnamed: C63.1, D1.C, IC10.1 (VI)
unnamed: D1.A, J1.1, J11.1
unnamed: C65.2, D2.A, IC11.2 (VI)
VCC: C4.+, L2.1; also elsewhere on the board
VEE: C5.-, L3.1, R37.1; also elsewhere on the board

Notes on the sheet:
cc-by-sa
Olivier Gillet
ol.gillet@gmail.com
Power
0.56mA needed
Wurth 742792664
0.68mA delivered
15V addition Christer Janson October 2018

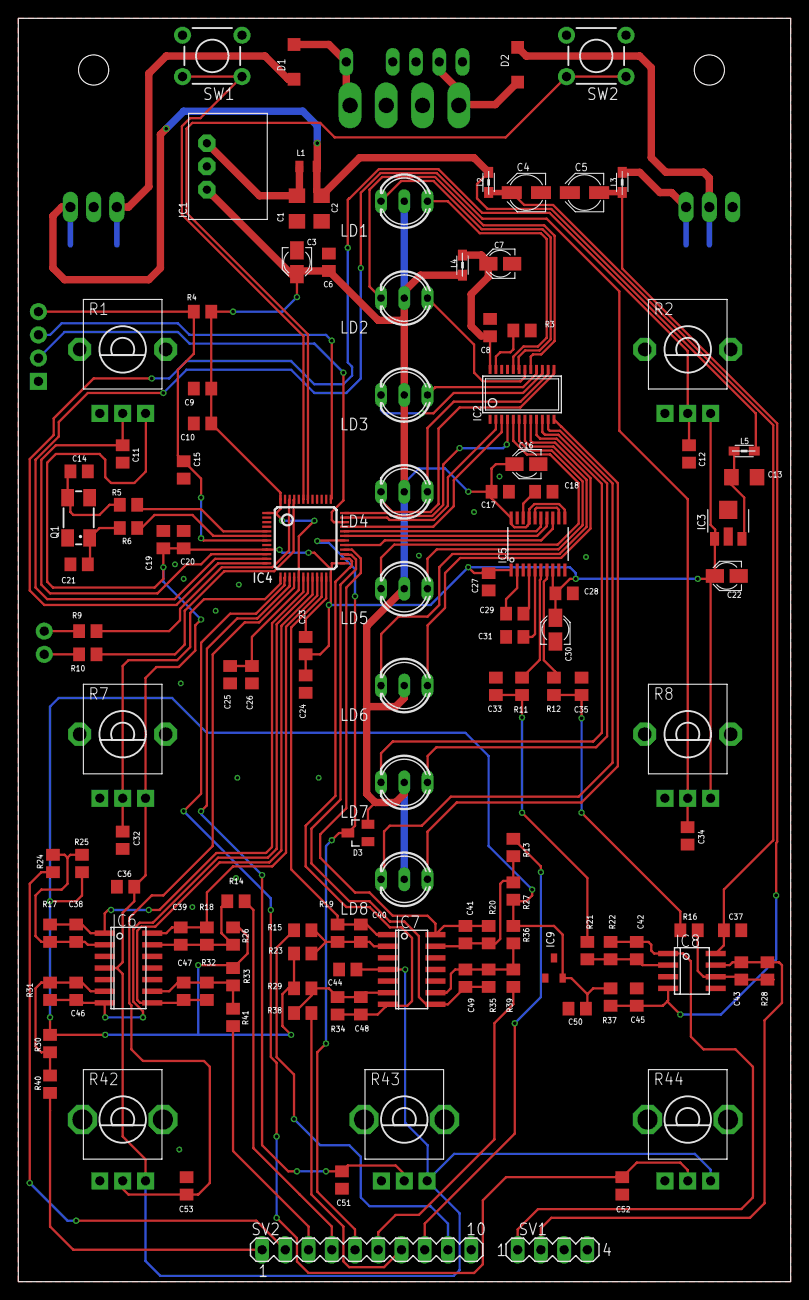
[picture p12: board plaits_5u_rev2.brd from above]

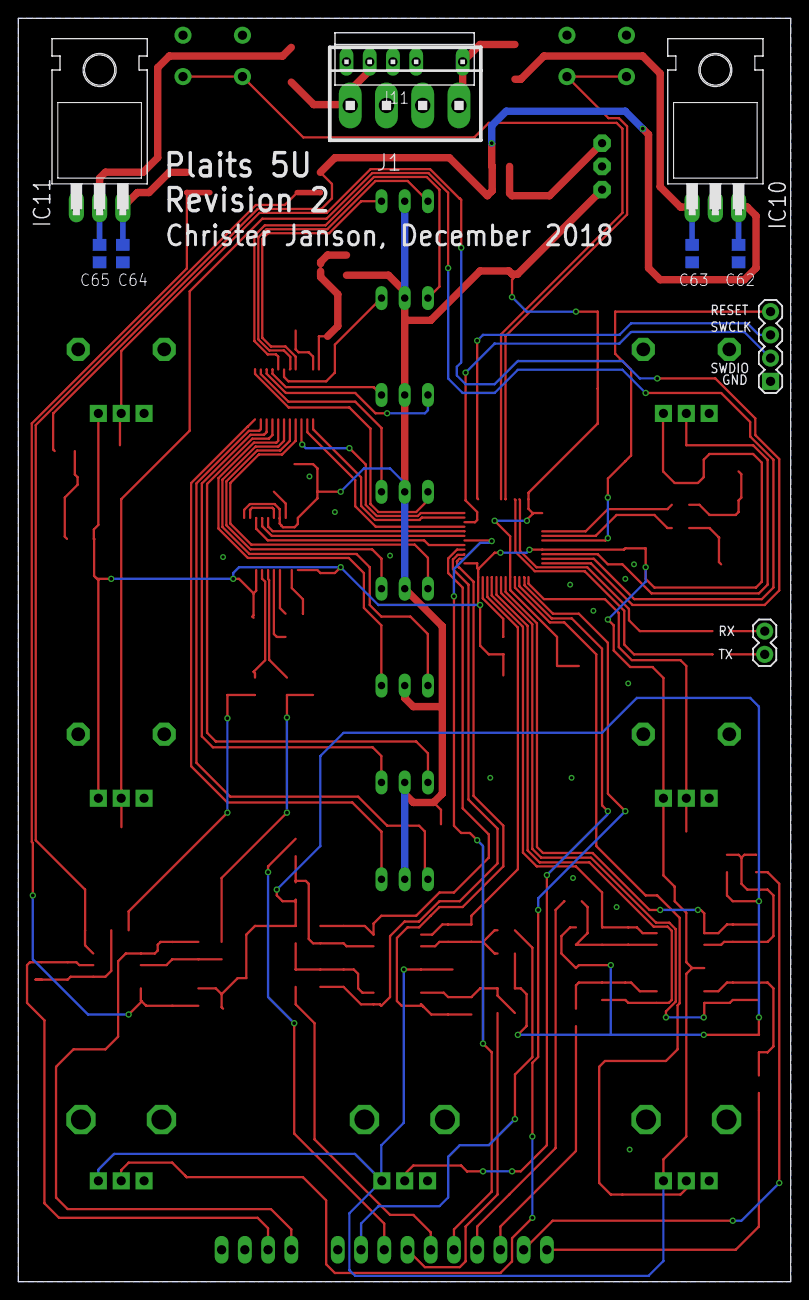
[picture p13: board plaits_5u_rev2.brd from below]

Board: 2 copper layers, 84.4 x 138.1 mm, 137 parts (10 on the bottom side), 95 nets.

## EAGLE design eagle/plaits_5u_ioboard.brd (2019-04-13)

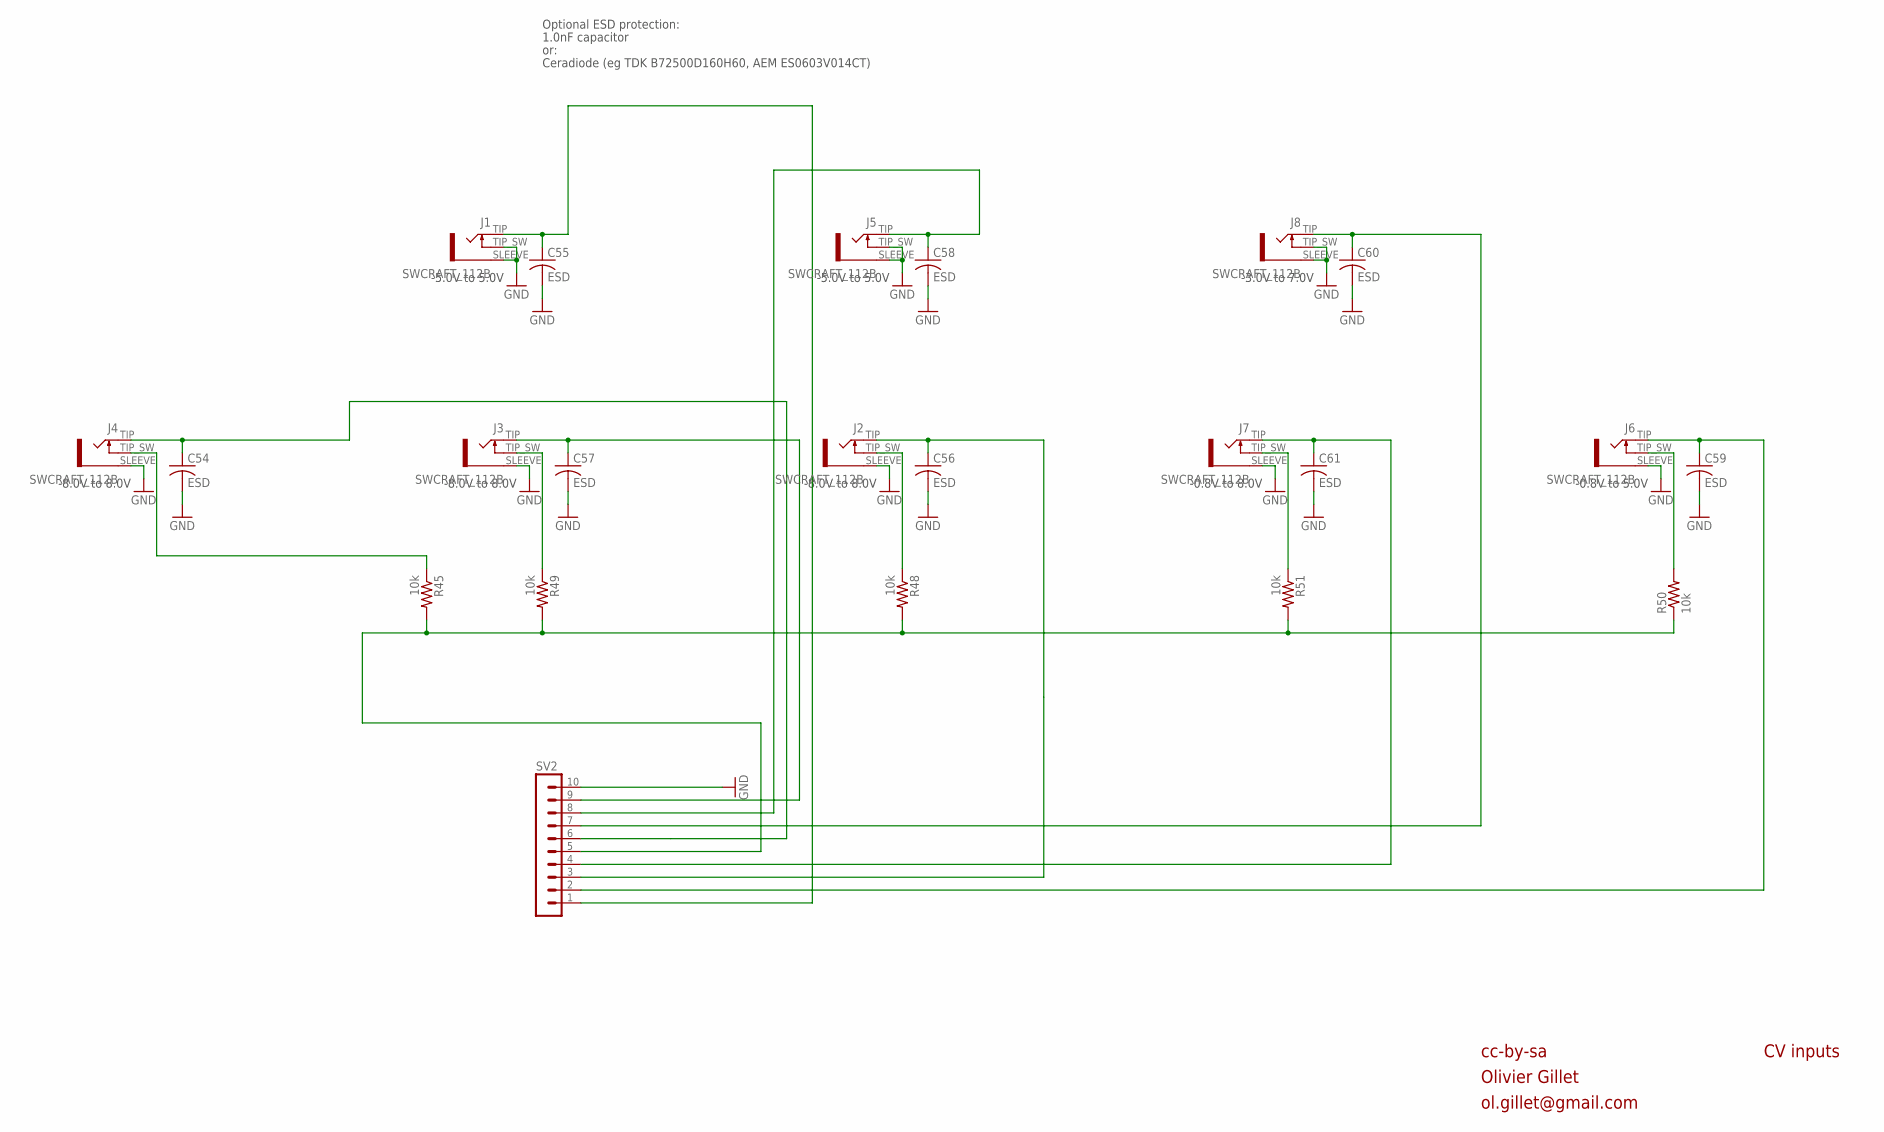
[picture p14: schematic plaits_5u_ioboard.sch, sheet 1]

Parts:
C54, C55, C56, C57, C58, C59, C60, C61: ESD; C0805
J1, J2, J3, J4, J5, J6, J7, J8: SWCRAFT_112B; SWCRAFT_112_SLOTS
R45, R48, R49, R50, R51: 10k; R0805
SV2: MA10-1

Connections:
FM_IN: C57.1, J3.TIP (3), SV2.9
GATE_IN: C61.1, J7.TIP (3), SV2.4
GATE_IN1: C59.1, J6.TIP (3), SV2.2
GND: C54.2, C55.2, C56.2, C57.2, C58.2, C59.2, C60.2, C61.2, J1.SLEEVE (5), J1.TIP_SW (4), J2.SLEEVE (5), J3.SLEEVE (5), J4.SLEEVE (5), J5.SLEEVE (5), J5.TIP_SW (4), J6.SLEEVE (5), J7.SLEEVE (5), J8.SLEEVE (5), J8.TIP_SW (4), SV2.10; also elsewhere on the board
HARMONICS_IN: C58.1, J5.TIP (3), SV2.8
MODEL_IN: C55.1, J1.TIP (3), SV2.1
MORPH_IN: C54.1, J4.TIP (3), SV2.6
unnamed: J6.TIP_SW (4), R50.2
unnamed: J3.TIP_SW (4), R49.1
unnamed: J2.TIP_SW (4), R48.1
unnamed: J4.TIP_SW (4), R45.1
unnamed: C56.1, J2.TIP (3), SV2.3
unnamed: J7.TIP_SW (4), R51.1
NORMALIZATION_PROBE: R45.2, R48.2, R49.2, R50.1, R51.2, SV2.5
V_OCT_IN: C60.1, J8.TIP (3), SV2.7

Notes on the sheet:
cc-by-sa
Olivier Gillet
ol.gillet@gmail.com
CV inputs
-3.0V to 7.0V
-8.0V to 8.0V
-5.0V to 5.0V
-0.8V to 8.0V
-0.8V to 5.0V
Optional ESD protection:
1.0nF capacitor
or:
Ceradiode (eg TDK B72500D160H60, AEM ES0603V014CT)

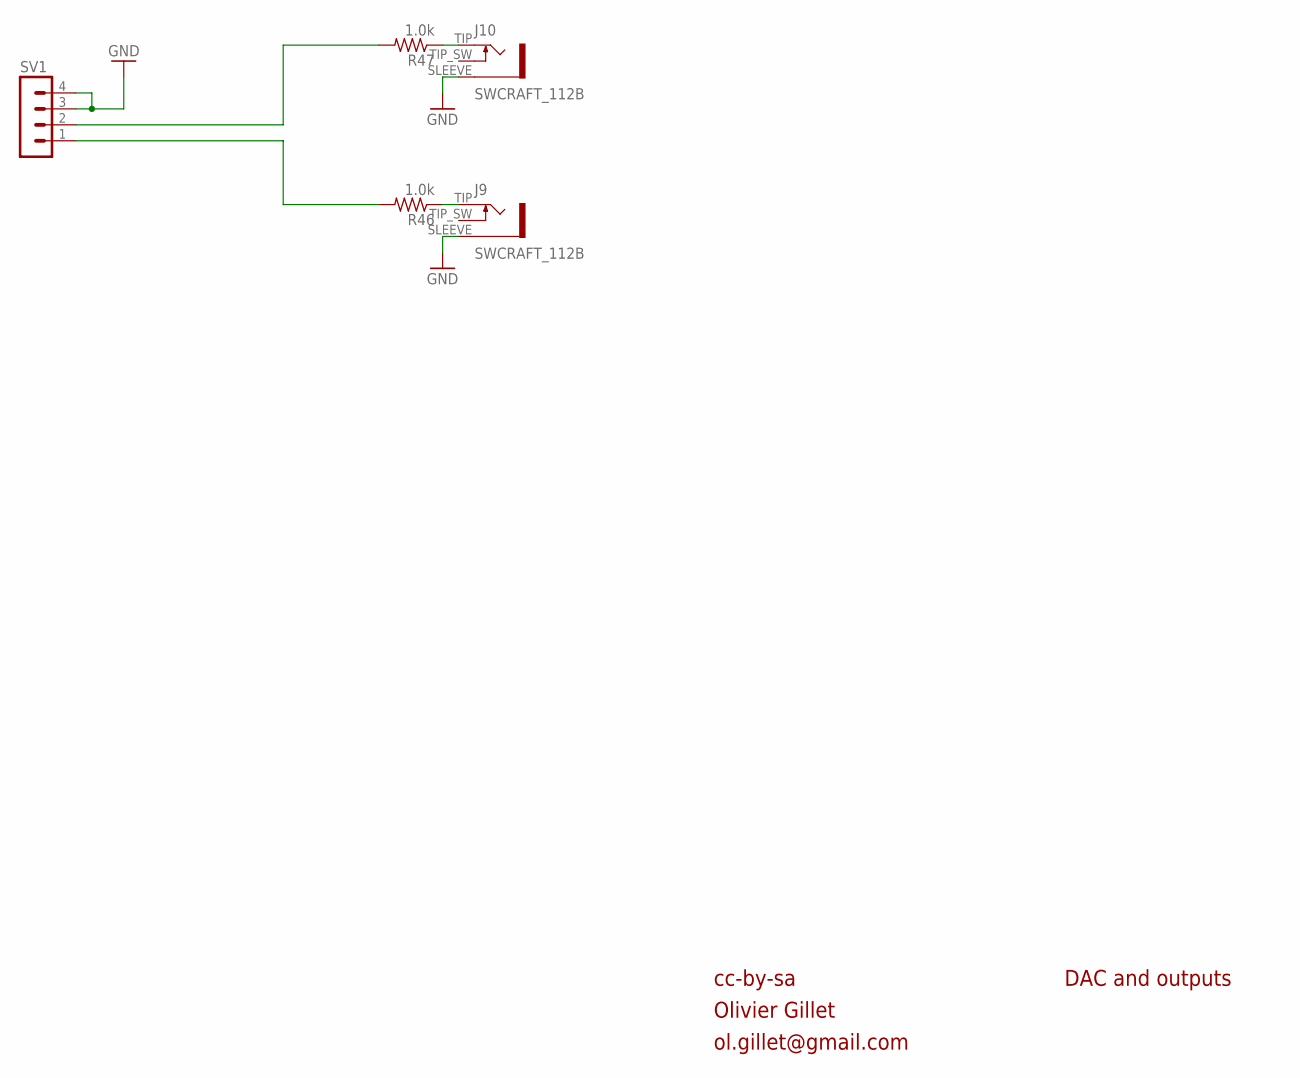
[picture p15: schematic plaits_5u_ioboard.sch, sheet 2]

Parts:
J9, J10: SWCRAFT_112B; SWCRAFT_112_SLOTS
R46, R47: 1.0k; R0805
SV1: MA04-1

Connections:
GND: J9.SLEEVE (5), J10.SLEEVE (5), SV1.3, SV1.4; also elsewhere on the board
unnamed: R46.2, SV1.1
unnamed: R47.2, SV1.2
unnamed: J9.TIP (3), R46.1
unnamed: J10.TIP (3), R47.1

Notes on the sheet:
cc-by-sa
Olivier Gillet
ol.gillet@gmail.com
DAC and outputs

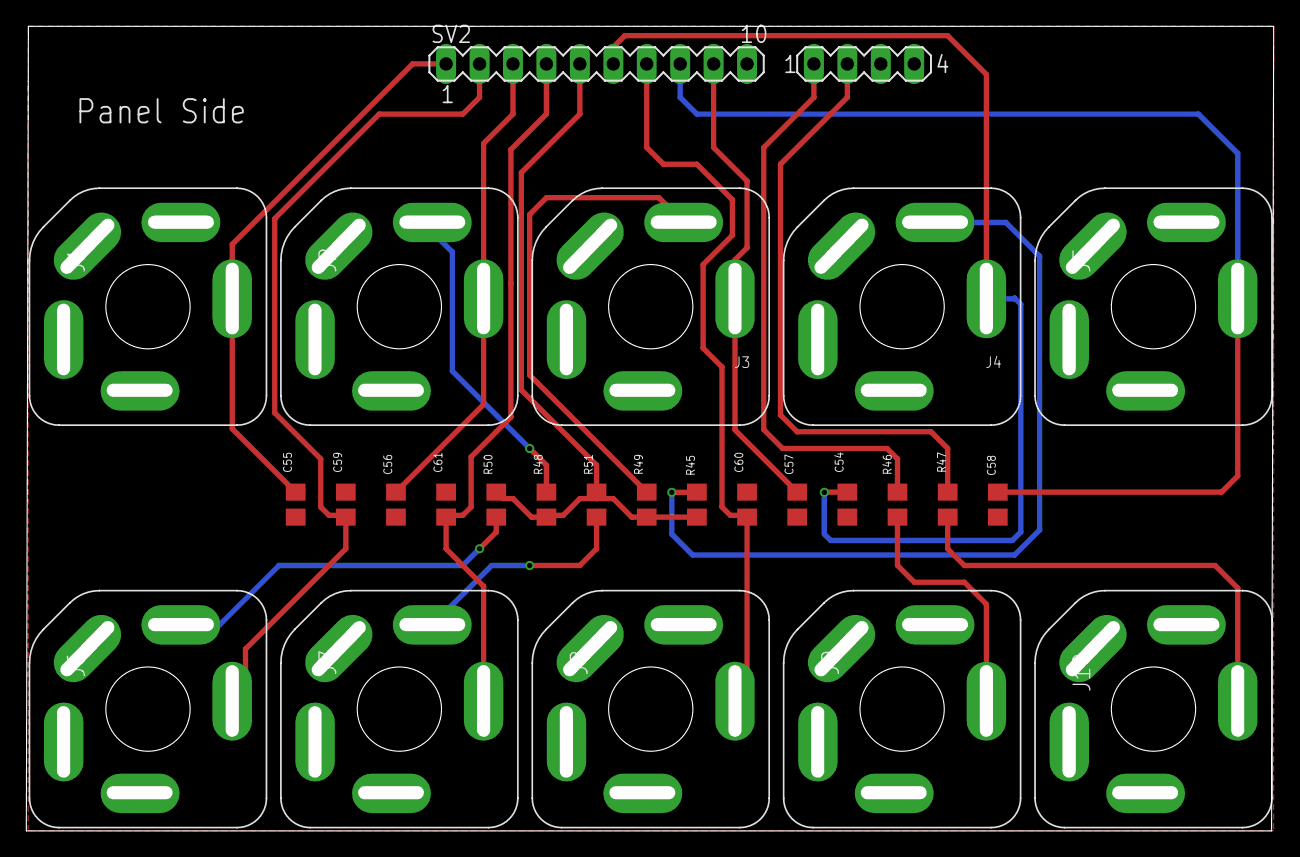
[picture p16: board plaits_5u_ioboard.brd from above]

Board: 2 copper layers, 94.8 x 61.1 mm, 27 parts (0 on the bottom side), 19 nets.

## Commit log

2019-04-13 Initial commit of Plaits Macro Oscillator ported to MU
    [MUPlaitsPanel.dwg, MUPlaitsPanel.dxf, plaits_5u_ioboard.brd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]
2019-04-14 Added BOM with MU component changes
    [PlaitsPartsMU.xlsx]
2019-04-14 Updated BOM and added photos of built module
    [PlaitsPartsMU.xlsx]
